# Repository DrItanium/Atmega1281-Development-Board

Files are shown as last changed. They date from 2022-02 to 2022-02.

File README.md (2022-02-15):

This is a simple development board for the QFP version of the ATMEGA1281. The
layout of the connector is an extended superset of the digital header found on
the Arduino Mega + an internal MajorCore development board I have also
created. 

The rest of the pins are laid out to make it trivial to design plugin boards
for my ecore and SxChipset projects.

The board is designed for the AISLER PCB manufacturing service.

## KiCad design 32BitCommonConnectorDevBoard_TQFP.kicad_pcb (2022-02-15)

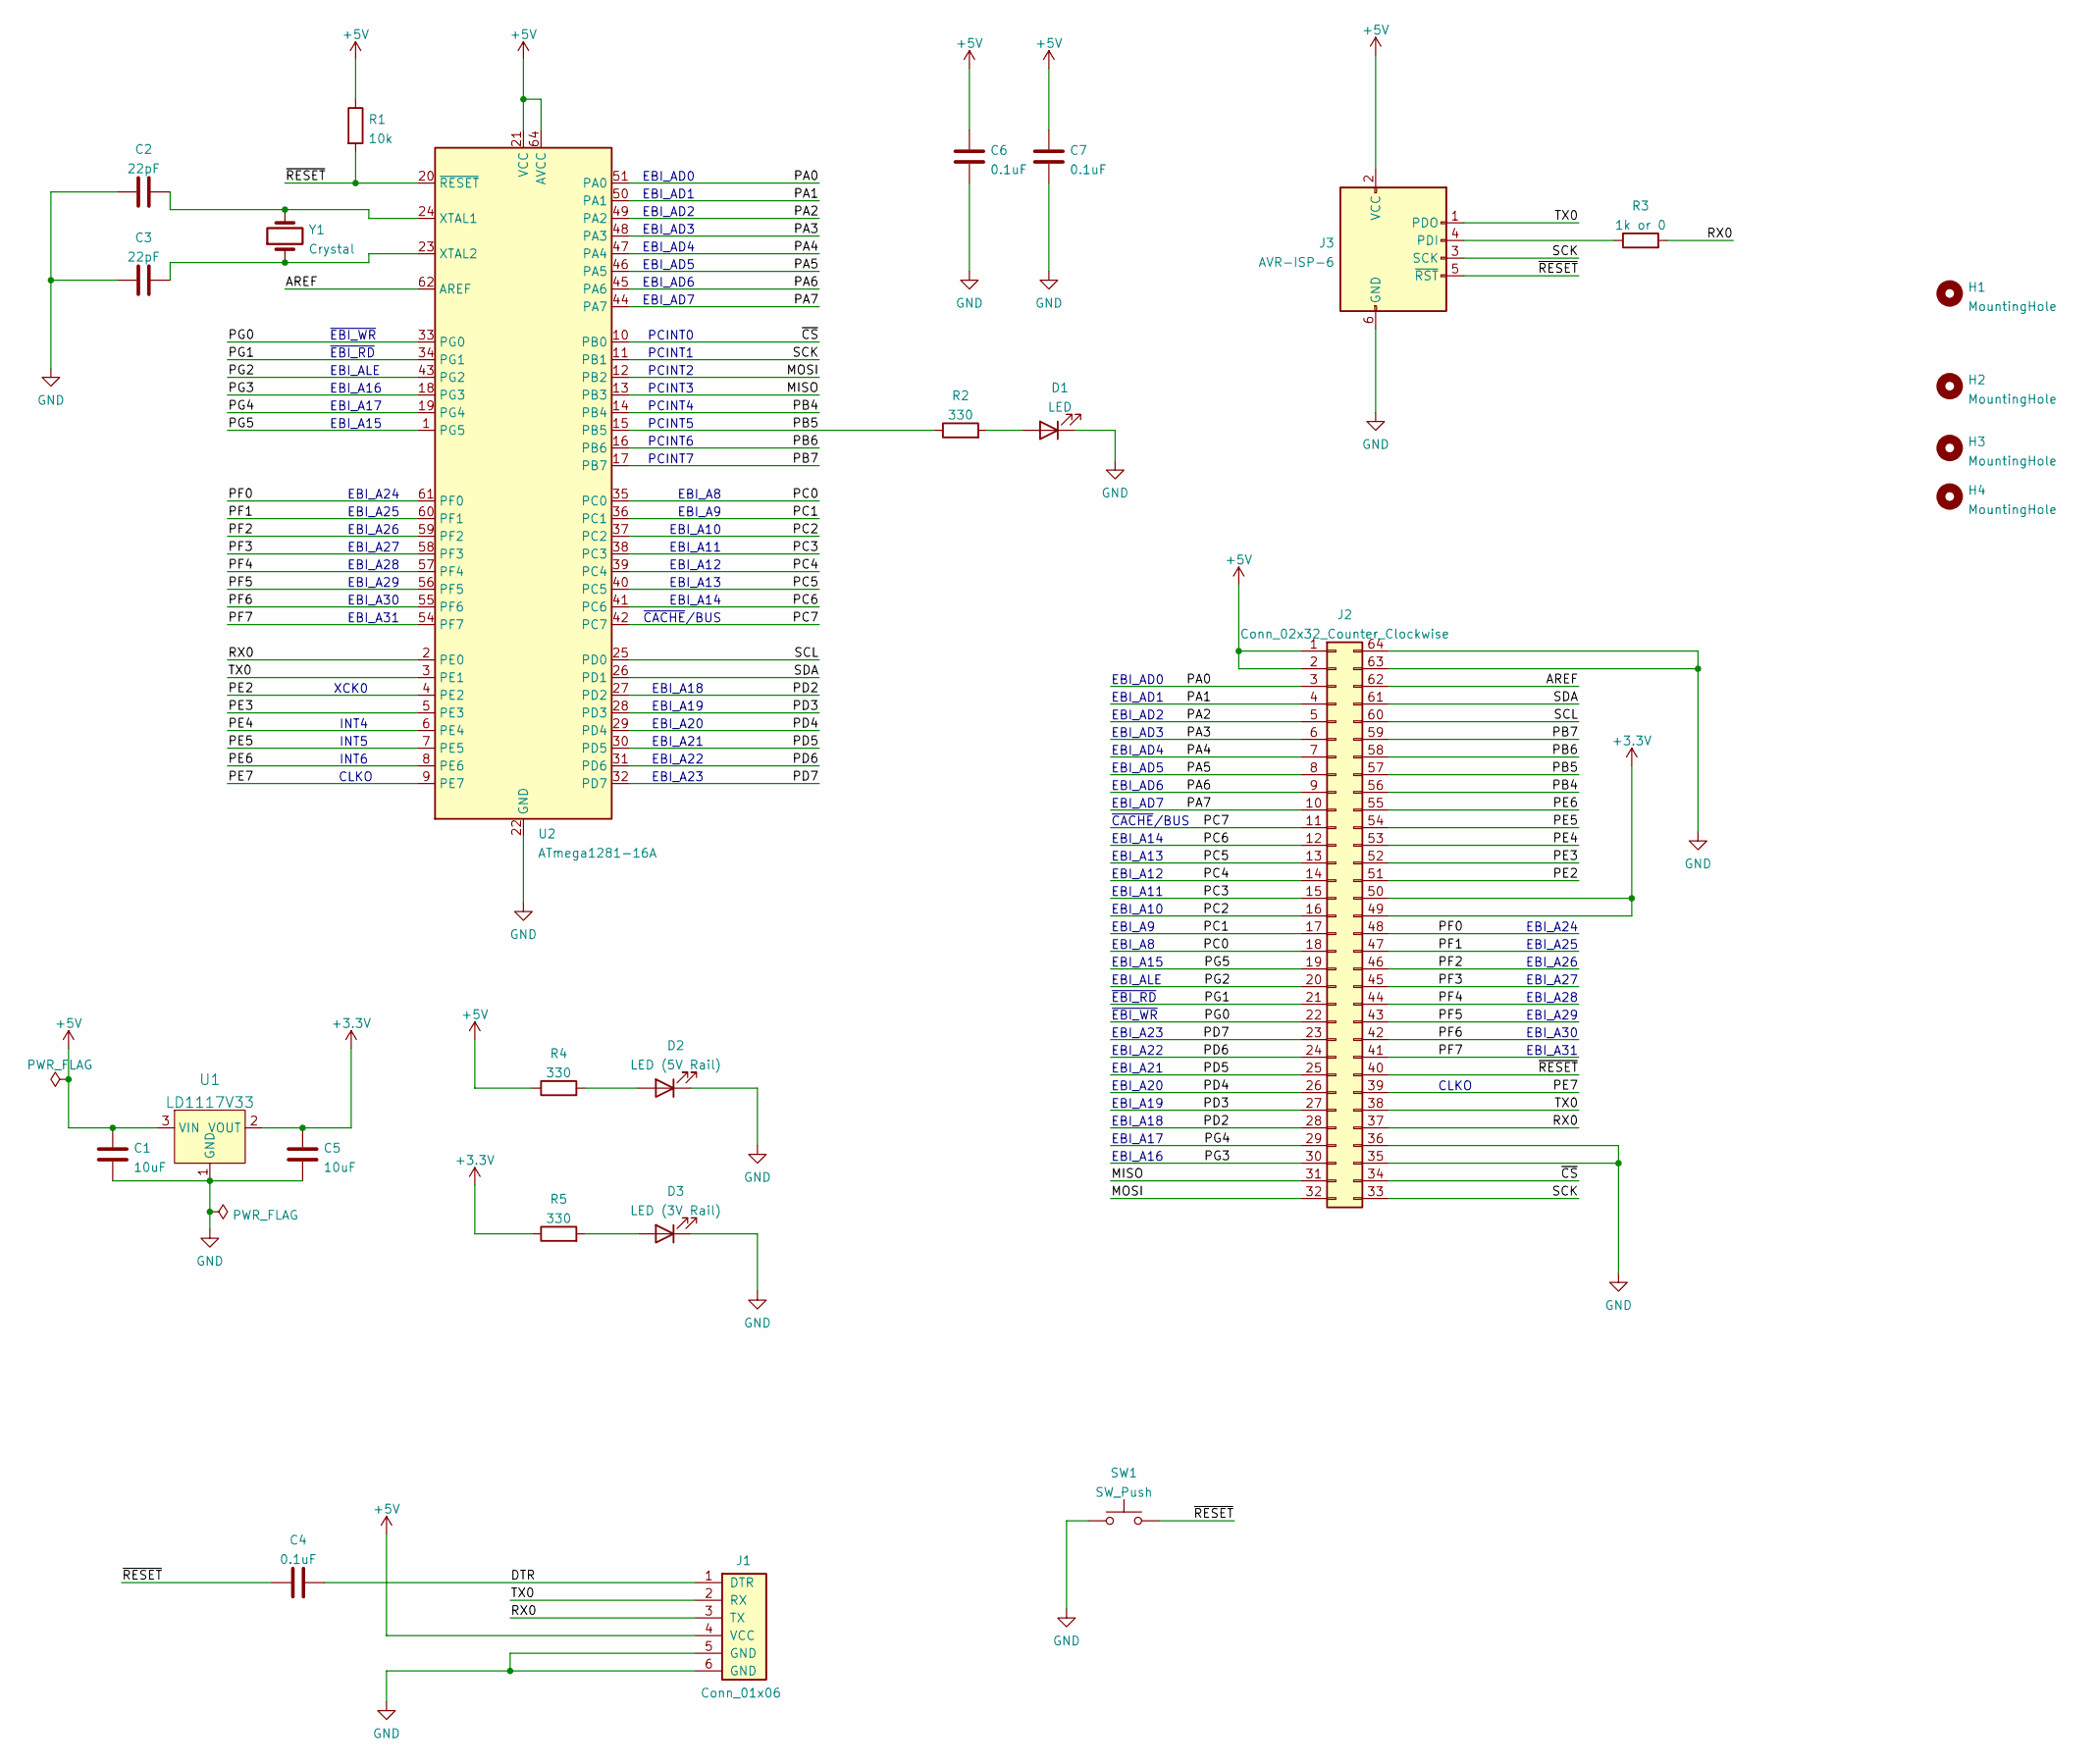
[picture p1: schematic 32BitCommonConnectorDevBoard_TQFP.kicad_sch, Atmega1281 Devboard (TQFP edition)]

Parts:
C1, C5: 10uF; C_0805_2012Metric_Pad1.18x1.45mm_HandSolder
C2, C3: 22pF; C_0805_2012Metric_Pad1.18x1.45mm_HandSolder
C4, C6, C7: 0.1uF; C_0805_2012Metric_Pad1.18x1.45mm_HandSolder
D1: LED; LED_D5.0mm
D2: LED (5V Rail); LED_D5.0mm
D3: LED (3V Rail); LED_D5.0mm
H1, H2, H3, H4: MountingHole; MountingHole_3.2mm_M3
J1: Conn_01x06; PinHeader_1x06_P2.54mm_Vertical
J2: Conn_02x32_Counter_Clockwise; PinSocket_2x32_P2.54mm_Vertical
J3: AVR-ISP-6; PinHeader_2x03_P2.54mm_Vertical
R1: 10k; R_0805_2012Metric_Pad1.20x1.40mm_HandSolder
R2, R4, R5: 330; R_0805_2012Metric_Pad1.20x1.40mm_HandSolder
R3: 1k or 0; R_0805_2012Metric_Pad1.20x1.40mm_HandSolder
SW1: SW_Push; SW_PUSH_6mm
U1: LD1117V33; TO-220-3; MPN LD1117V33; Digi-Key_PN 497-1491-5-ND
U2: ATmega1281-16A; TQFP-64_14x14mm_P0.8mm
Y1: Crystal; Crystal_HC49-U_Vertical

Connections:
+3V3: C5.1, J2.49, J2.50, R5.1, U1.2 (VOUT)
+5V: C1.1, C6.1, C7.1, J1.4 (VCC), J2.1, J2.2, J3.2 (VCC), R1.1, R4.1, U1.3 (VIN), U2.21 (VCC), U2.52 (VCC), U2.64 (AVCC)
/AREF: J2.62, U2.62 (AREF)
/DTR: C4.1, J1.1 (DTR)
/MISO: J2.31, U2.13 (PB3)
/MOSI: J2.32, U2.12 (PB2)
/PA0: J2.3, U2.51 (PA0)
/PA1: J2.4, U2.50 (PA1)
/PA2: J2.5, U2.49 (PA2)
/PA3: J2.6, U2.48 (PA3)
/PA4: J2.7, U2.47 (PA4)
/PA5: J2.8, U2.46 (PA5)
/PA6: J2.9, U2.45 (PA6)
/PA7: J2.10, U2.44 (PA7)
/PB4: J2.56, U2.14 (PB4)
/PB5: J2.57, R2.1, U2.15 (PB5)
/PB6: J2.58, U2.16 (PB6)
/PB7: J2.59, U2.17 (PB7)
/PC0: J2.18, U2.35 (PC0)
/PC1: J2.17, U2.36 (PC1)
/PC2: J2.16, U2.37 (PC2)
/PC3: J2.15, U2.38 (PC3)
/PC4: J2.14, U2.39 (PC4)
/PC5: J2.13, U2.40 (PC5)
/PC6: J2.12, U2.41 (PC6)
/PC7: J2.11, U2.42 (PC7)
/PD2: J2.28, U2.27 (PD2)
/PD3: J2.27, U2.28 (PD3)
/PD4: J2.26, U2.29 (PD4)
/PD5: J2.25, U2.30 (PD5)
/PD6: J2.24, U2.31 (PD6)
/PD7: J2.23, U2.32 (PD7)
/PE2: J2.51, U2.4 (PE2)
/PE3: J2.52, U2.5 (PE3)
/PE4: J2.53, U2.6 (PE4)
/PE5: J2.54, U2.7 (PE5)
/PE6: J2.55, U2.8 (PE6)
/PE7: J2.39, U2.9 (PE7)
/PF0: J2.48, U2.61 (PF0)
/PF1: J2.47, U2.60 (PF1)
/PF2: J2.46, U2.59 (PF2)
/PF3: J2.45, U2.58 (PF3)
/PF4: J2.44, U2.57 (PF4)
/PF5: J2.43, U2.56 (PF5)
/PF6: J2.42, U2.55 (PF6)
/PF7: J2.41, U2.54 (PF7)
/PG0: J2.22, U2.33 (PG0)
/PG1: J2.21, U2.34 (PG1)
/PG2: J2.20, U2.43 (PG2)
/PG3: J2.30, U2.18 (PG3)
/PG4: J2.29, U2.19 (PG4)
/PG5: J2.19, U2.1 (PG5)
/RX0: J1.3 (TX), J2.37, R3.2, U2.2 (PE0)
/SCK: J2.33, J3.3 (SCK), U2.11 (PB1)
/SCL: J2.60, U2.25 (PD0)
/SDA: J2.61, U2.26 (PD1)
/TX0: J1.2 (RX), J2.38, J3.1 (PDO), U2.3 (PE1)
/~CS: J2.34, U2.10 (PB0)
/~RESET: C4.2, J2.40, J3.5 (~RST), R1.2, SW1.2, U2.20 (~RESET)
GND: C1.2, C2.1, C3.1, C5.2, C6.2, C7.2, D1.1 (K), D2.1 (K), D3.1 (K), J1.5 (GND), J1.6 (GND), J2.35, J2.36, J2.63, J2.64, J3.6 (GND), SW1.1, U1.1 (GND), U2.22 (GND), U2.53 (GND), U2.63 (GND)
unnamed: C2.2, U2.24 (XTAL1), Y1.2
unnamed: C3.2, U2.23 (XTAL2), Y1.1
unnamed: D1.2 (A), R2.2
unnamed: D2.2 (A), R4.2
unnamed: D3.2 (A), R5.2
unnamed: J3.4 (PDI), R3.1

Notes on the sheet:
EBI_A27
INT4
EBI_A29
INT5
CLKO
EBI_A21
EBI_A17
EBI_A31
PCINT3
EBI_A8
PCINT2
EBI_A28
EBI_A12
EBI_AD5
EBI_A24
EBI_A16
PCINT0
EBI_AD0
EBI_A14
EBI_A19
EBI_AD7
EBI_AD3
EBI_A13
EBI_A22
EBI_AD4
PCINT6
EBI_A23
EBI_AD1
~{EBI_RD}
EBI_AD6
~{CACHE}/BUS
PCINT1
EBI_A26
EBI_ALE
EBI_A25
PCINT5
XCK0
PCINT7
~{EBI_WR}
INT6

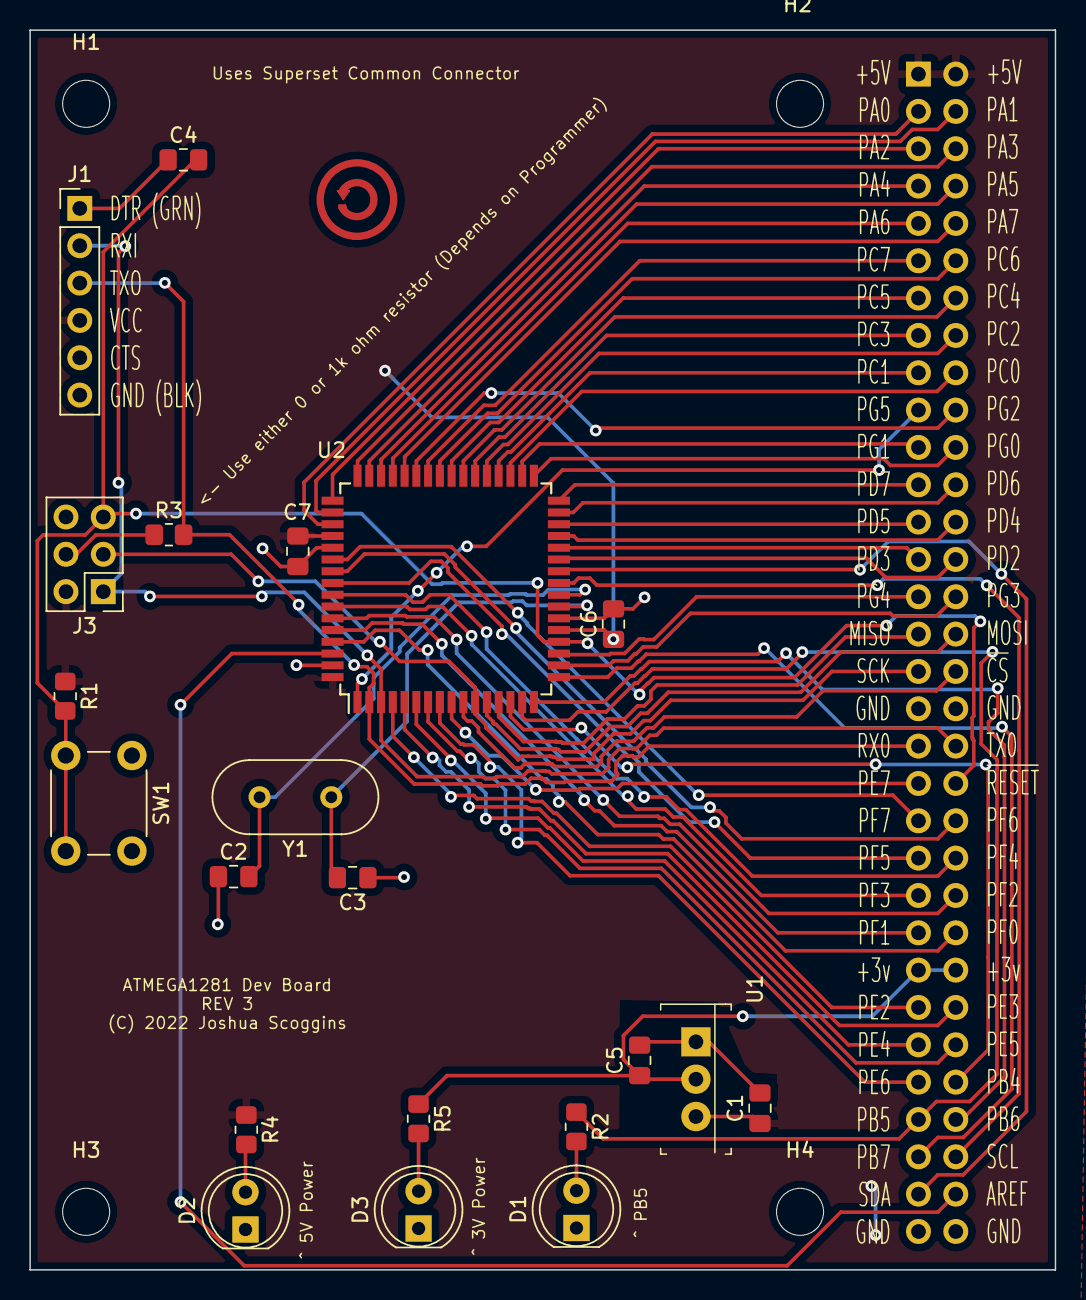
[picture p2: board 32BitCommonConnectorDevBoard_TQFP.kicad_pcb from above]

Board: 2 copper layers, 69.8 x 84.3 mm, 26 parts (1 on the bottom side), 66 nets.

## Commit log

2022-02-15 Rename the schematic pins to reflect port ids
    The EBI layout is implied by the design
    [32BitCommonConnectorDevBoard_TQFP.kicad_sch]
2022-02-15 Clean up layouts and shrink board slightly
    [32BitCommonConnectorDevBoard_TQFP.kicad_pcb, 32BitCommonConnectorDevBoard_TQFP.kicad_sch]
2022-02-15 Move PE7 to position 39 on the connector
    PG5 is now in place of PB7
    Rearrange left over port B so it is:
    59 -> PB7
    58 -> PB6
    57 -> PB5
    56 -> PB4
    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
    [32BitCommonConnectorDevBoard_TQFP.kicad_sch]
2022-02-15 Update revision number and put share alike logo back in
    [32BitCommonConnectorDevBoard_TQFP.kicad_pcb]

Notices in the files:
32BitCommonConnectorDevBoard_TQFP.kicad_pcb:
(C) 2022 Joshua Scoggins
